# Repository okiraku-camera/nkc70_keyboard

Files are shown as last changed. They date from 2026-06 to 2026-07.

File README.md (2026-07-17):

# nkc70_keyboard

このリポジトリは、`nkc70` キーボードの KiCad 8 用ハードウェア設計データを管理するためのものです。

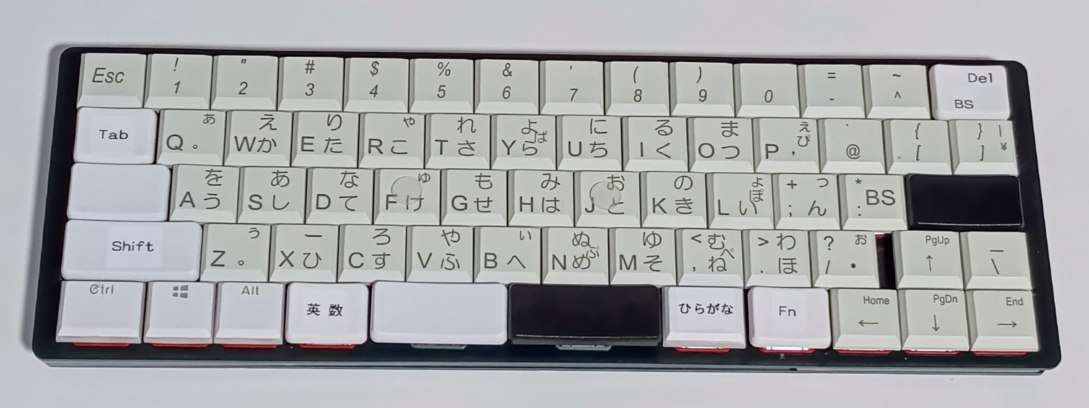
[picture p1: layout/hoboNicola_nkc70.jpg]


## nkc70キーボードについて
`nkc70` キーボードは、ロープロファイルなキースイッチの代表格である Kailh Choc V1 スイッチを用いた `hoboNicolaキーボード` です。以下のような特長があります。

- 親指シフトキーボードに準じた配列とし、親指キー同時打鍵による入力ができる。
- 1U サイズとして 18 x 17 mm の最小ピッチを採用。
- 一般的な 60% キーボードから 1 列減らすことで、横幅を 20 mm ほど縮小。
- スイッチプレート、PCB、ボトムプレートの 3 枚の FR-4 プレートと、5 mm 厚のアクリル板によるサポートで構成。
- キースイッチは65個、2Uキーキャップ用スタビライザーを3個使用。
- キーキャップ交換が容易になるように、Kailh スイッチソケット (CPG135001S30) を PCB に装着。
- 厚さは、プレート部分が約 10 mm、その上のスイッチとキーキャップが約 8 mm で、合計 18 mm ほど。
- マイコンは RP2040 を採用。スイッチマトリックスは 5 x 14 (70 ポジション) 。

Kailh Choc V1 スイッチ用のスタビライザーを使う上での検討内容については、別途 [ブログ記事](https://okiraku-camera.tokyo/blog/?p=17262) にまとめています。

## レイアウト
このプロジェクトでは、以下のようなレイアウトの hoboNicola キーボードを実現することを前提としています。

### 日本語レイアウトで使うとき

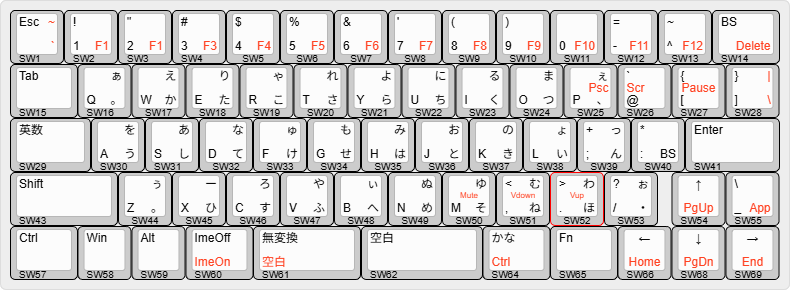
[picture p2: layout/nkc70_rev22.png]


### USレイアウトで使うとき

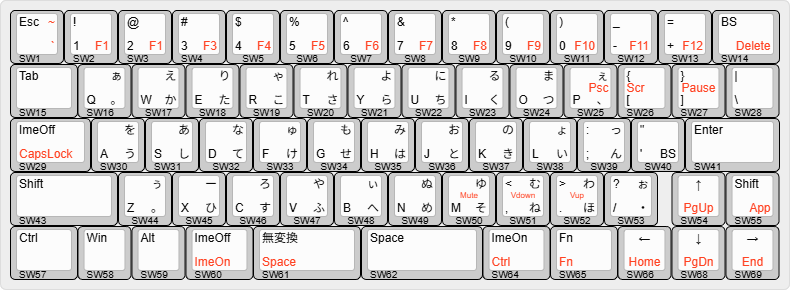
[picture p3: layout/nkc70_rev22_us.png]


### レイアウトについて
- 赤字で示したレジェンドは、Fn キーを押下中の場合の出力を示しています。
- 図中の ImeOn、ImeOff という表記は、HID の LANG0/LANG1 相当のコードを表しています。
- 無変換、変換、かなといった表記は、Windows でのキーです。
- 無変換キーや変換キーは、macOS では無効です。ただ、Ubuntu などの Linux 環境では ANSI レイアウトであっても IME 操作に利用することができます。
- ホスト側のハードウェアキーボードとして英語キーボードレイアウト (ANSI レイアウト) に設定しているときは、本キーボードを USレイアウトとします。
- US レイアウトの CapsLock が Fn 側になっているのは、CapsLock キーで IME を英字に切り替えたいとき、CapsLock がオンにならないようにするための配慮です。

### 構造と組立て
FR-4 プレートとアクリルサポートにより、以下のような構造になります。

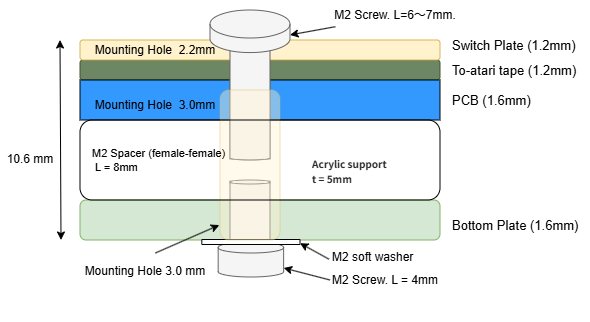
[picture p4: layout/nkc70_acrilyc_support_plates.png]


組み立てには、M2 サイズの皿ネジと M2 サイズの真鍮スペーサー (female-female、8 mm 長) を用います。

## 各ディレクトリの内容

- `layout/`
  - KLE で作成したキー配列定義データです。
  - 日本語配列用の `nkc70_rev22.json` と、US 配列用の `nkc70_rev22_us.json` を含みます。

- `pcb/`
  - メイン PCB の設計データです。
  - 1.6 mm 厚の FR-4 プレートで作ることを前提としています。
  - 回路図（`*.kicad_sch`）と配線図/基板レイアウト（`*.kicad_pcb`）、プロジェクト内ライブラリ（`lib/`）を含みます。
  - `lib/nklib.kicad_sym` には、回路図で使っているいくつかのシンボル定義を含んでいます。回路では、`local` というニックネームで修飾しています。
  - `lib` ディレクトリには、この PCB で使っているいくつかのデバイスのフットプリントを含んでいます。
  - `lib/kiswitch` ディレクトリには、GitHub の kiswitch リポジトリからダウンロードした、Choc V1 スイッチのいくつかのフットプリントを含んでいます。

- `swplate/`
  - スイッチプレート用の設計データです。
  - 1.2 mm 厚の FR-4 プレートで作ることを前提としています。
  - メイン PCB の PCB 図を基に、スイッチ用フットプリントを、スイッチをはめるための Edge.Cuts で描いた矩形のみのフットプリント (`ChocV1_hole138.kicad_mod`) に置き換えて生成しています。
  - 2U および 2.25U のスイッチ用フットプリントについては、スタビライザー用のカットアウトを持つフットプリントに置き換えています。
  - ネジ穴が他のプレートとずれないようにしながら、外形サイズを PCB より大きくしています。

- `bplate/`
  - ボトムプレート（底板）用の設計データです。
  - 1.6 mm 厚の FR-4 プレートで作ることを前提としています。
  - 人目に触れる側 (B 面) は、銅箔の塗りつぶしエリアと塗りつぶし禁止ゾーンを使った市松模様としています。

- `acrylic/`
  - PCB とボトムプレート間に配置するアクリルサポート用の設計データおよびカット用ファイルを含みます。
  - PCB エディターでアクリルカット用の外形データを設計しています。
  - アクリルカットの発注用に出力した `dxf` および `pdf` ファイルを含んでいます。
  - アクリルサポートの外形、ネジ穴位置は PCB や他のプレートと密接に関係しています。`pcb` ディレクトリや `bplate` にある PCB 図面に User.4 で描いている外形をもとに、アクリルカットの発注用にまとめています。

## 免責事項

本ハードウェア設計データは「AS IS」で提供されています。本設計データまたは本設計データから製造・組立てされたハードウェアについて、いかなる保証もいたしません。本設計データの使用に伴う損害については、一切の責任を負いません。

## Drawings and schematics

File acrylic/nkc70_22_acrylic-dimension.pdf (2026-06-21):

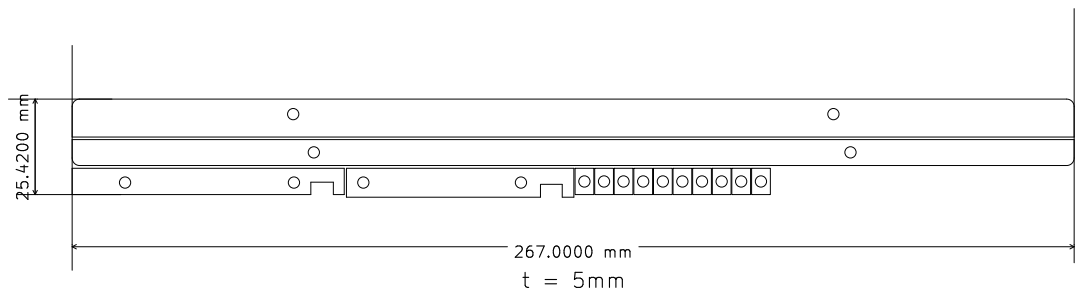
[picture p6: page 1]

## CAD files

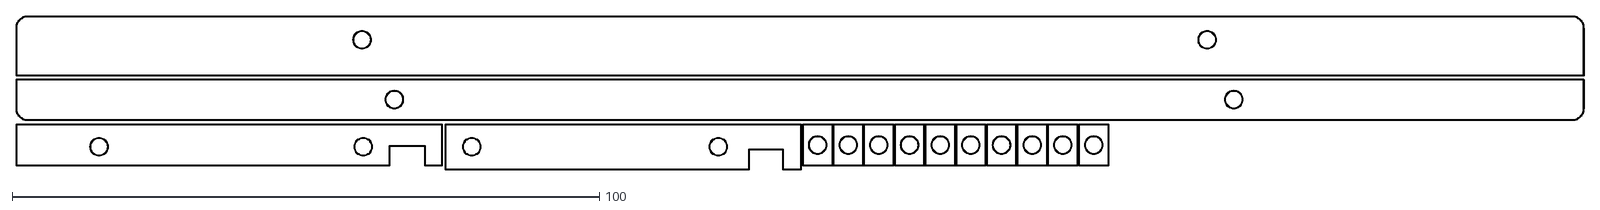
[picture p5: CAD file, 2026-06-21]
acrylic/nkc70_22_acrylic-cutout.dxf
267.1 x 26.2
